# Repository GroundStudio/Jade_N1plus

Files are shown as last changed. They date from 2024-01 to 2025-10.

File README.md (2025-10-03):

GroundStudio Jade N1+
====================================
JadeN1+

Get it from [ardushop.ro](https://ardushop.ro/en/groundstudio/1403-jade-n1-rev100-6427854020598.html)

Explore all the GroundStudio products at [ardushop.ro](https://ardushop.ro/en/37-groundstudio)

Description
-------------------
ATMEGA328PB based development board featuring picoPower® technology for better power management, Peripheral Touch Controller (PTC), 32kBytes of In-System Self-Programmable Flash program memory,  1kBytes EEPROM, 2kBytes Internal SRAM, 9 PWM Channels, 22 Digital Pins, 2 USART, 2 SPI, 2 I²C, 8 ADC Pins with 10 bit Resolution and HT42B534-2 for USB comunication.

Contents
-------------------

* [/Documentation](https://github.com/GroundStudio/Jade_N1plus/tree/main/Documentation) -- Pinout.
* [/Hardware](https://github.com/GroundStudio/Jade_N1plus/tree/main/Hardware) -- Schematics, layout.

Versions
-------------------
*(Not all tags shown)*
- [REV1.0.0]:

License
-------------------

This is released under the [Attribution-ShareAlike 4.0 International (CC BY-SA 4.0)](https://creativecommons.org/licenses/by-sa/4.0/) license. 
**You are welcome to use this for commercial purposes.**

Please consider contributing back to this project or others to help the open-source hardware community continue to thrive and grow! 

Certifications:

[Open Source Hardware Association](https://certification.oshwa.org/ro000023.html)   
   
certification-mark-RO000023-wide (https://certification.oshwa.org/ro000023.html)

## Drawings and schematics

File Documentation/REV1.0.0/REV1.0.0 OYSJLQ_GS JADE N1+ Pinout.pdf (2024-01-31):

# GroundStudio Jade N1+

PC6

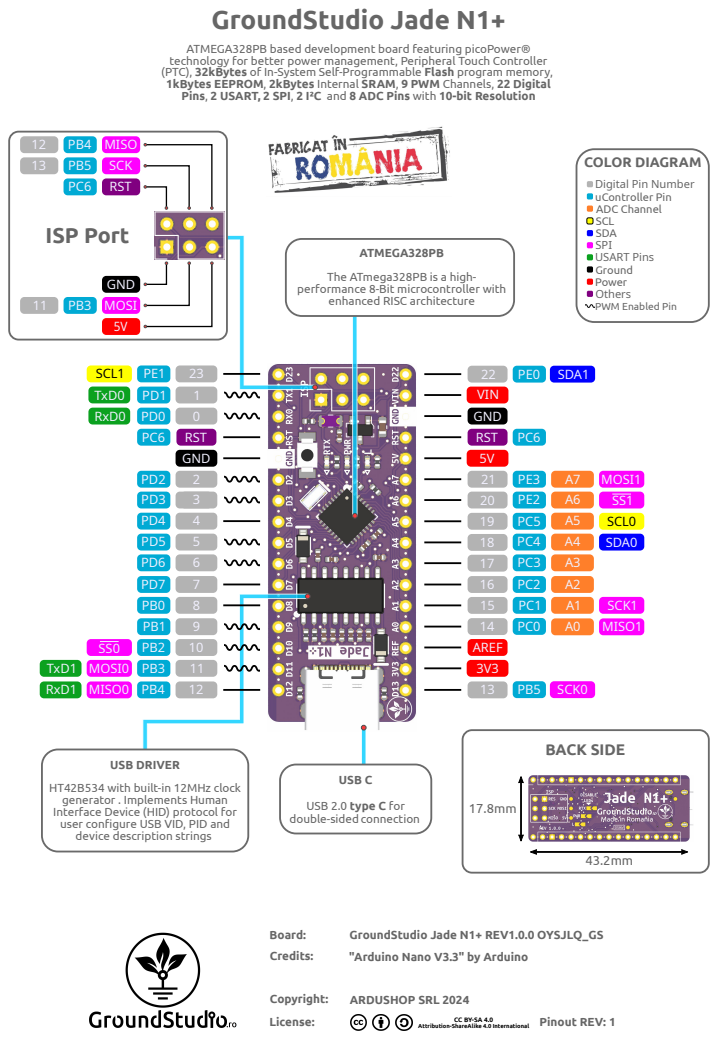
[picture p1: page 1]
SDA1; VIN; GND RST; 17 16 15 14 AREF; PB5 SCK0; MISO0; MOSI0; GND; RST; GND MOSI 5V; SCK; MISO; ISP Port; USB DRIVER; TxD0 RxD0; TxD1 RxD1; SDA0; SCL0; MISO1; MOSI1; SCK1; BACK SIDE; USB C; Board:; Credits:; Copyright:; License:; ARDUSHOP SRL 2024; Pinout REV: 1; SCL1

ATMEGA328PB based development board featuring picoPower®
technology for better power management, Peripheral Touch Controller
(PTC), 32kBytes of In-System Self-Programmable Flash program memory,
1kBytes EEPROM, 2kBytes Internal SRAM, 9 PWM Channels, 22 Digital
Pins, 2 USART, 2 SPI, 2 I²C and 8 ADC Pins with 10-bit Resolution

COLOR DIAGRAM
Digital Pin Number
uController Pin
ADC Channel
SCL
SDA
SPI
USART Pins
Ground
Power
Others
PWM Enabled Pin

ATMEGA328PB
The ATmega328PB is a high-
performance 8-Bit microcontroller with
enhanced RISC architecture

HT42B534 with built-in 12MHz clock
generator . Implements Human
Interface Device (HID) protocol for
user configure USB VID, PID and
device description strings

USB 2.0 type C for
double-sided connection

GroundStudio Jade N1+ REV1.0.0 OYSJLQ_GS
"Arduino Nano V3.3" by Arduino

Attribution-ShareAlike 4.0 International

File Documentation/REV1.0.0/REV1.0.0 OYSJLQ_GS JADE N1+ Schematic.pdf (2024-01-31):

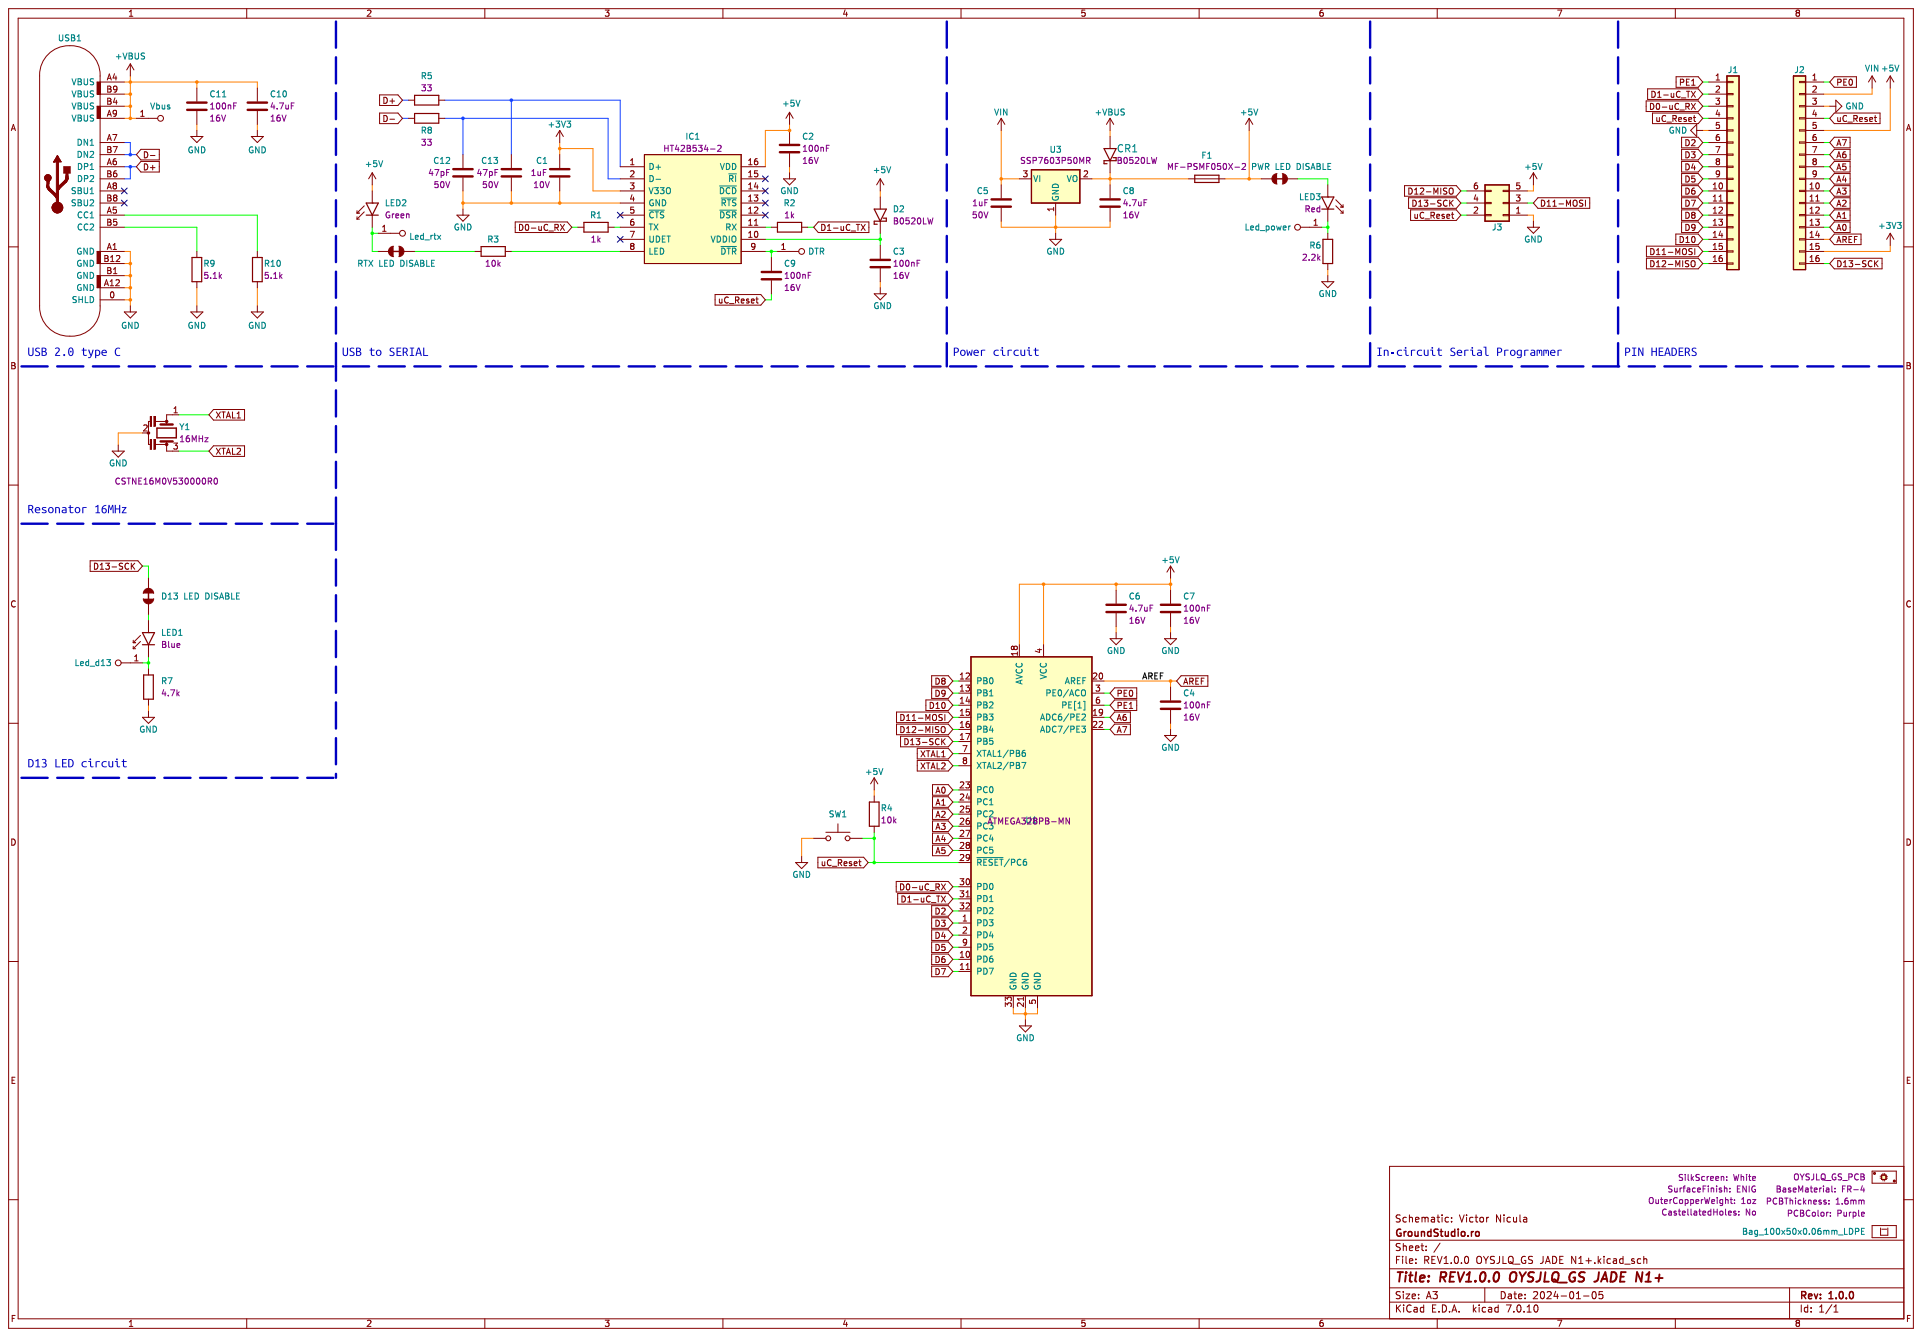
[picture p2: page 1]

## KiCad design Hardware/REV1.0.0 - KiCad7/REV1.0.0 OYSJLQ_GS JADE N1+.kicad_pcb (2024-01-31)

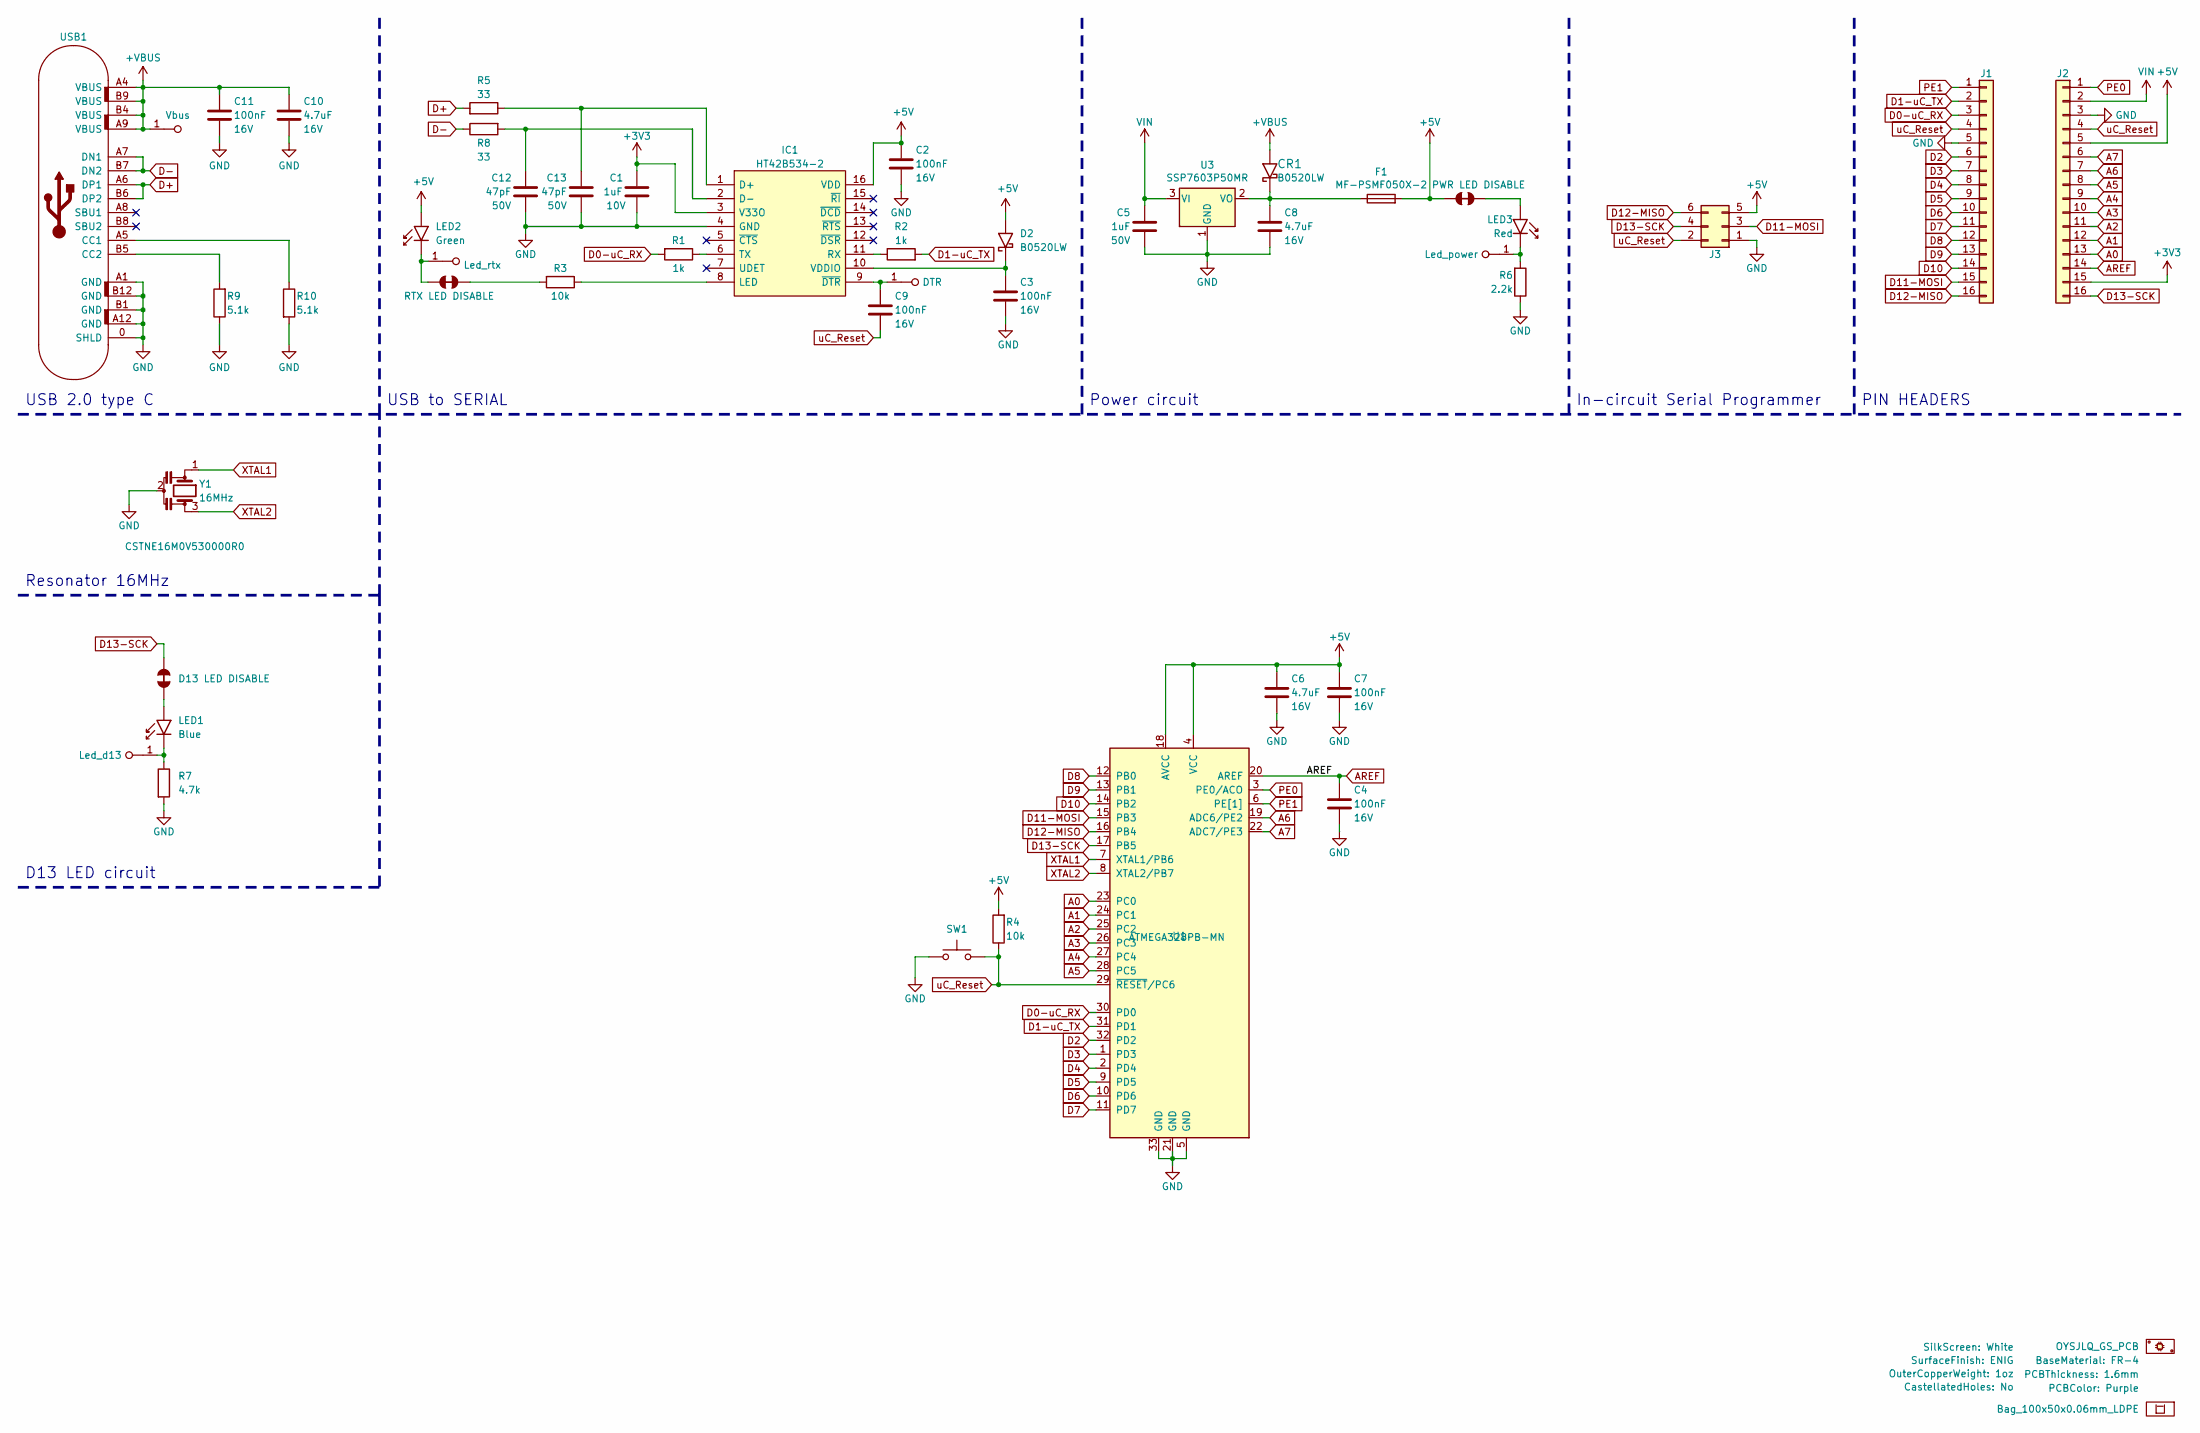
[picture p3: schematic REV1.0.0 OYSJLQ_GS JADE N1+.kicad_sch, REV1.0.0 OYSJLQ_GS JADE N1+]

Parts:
B1: Bag_100x50x0.06mm_LDPE; MPN KFHHEG_B
C1: C_0402_1uF_10V; C_0402_alt; Rated voltage 10V; MPN FS15B105K100PKG; LCSC C525324
C2, C4, C7, C9, C11: C_0402_100nF_16V; C_0402_alt; Rated voltage 16V; MPN 0402B104K160CT; LCSC C83056
C3: C_0402_100nF_16V; C_0402_alt; MPN 0402B104K160CT; LCSC C83056
C5: C_0603_1uF_50V; C_0603; Rated voltage 50V; MPN CL10A105KB8NNNC; LCSC C15849
C6, C8, C10: C_0402_4.7uF_16V; C_0402_alt; Rated voltage 16V; MPN C0402X5R475M160NT; LCSC C729453
C12, C13: C_0402_47pF_50V; C_0402_alt; Rated voltage 50V; MPN FN15N470J500PNG; LCSC C525215
CR1: SOD-123 B0520LW; SOD-123; MPN B0520LW; LCSC C89640
D2: SOD-123 B0520LW; SOD-123; MPN B0520LW; LCSC C89640
F1: Fuse_0805_MF-PSMF050X-2; Fuse_0805; MPN MF-PSMF050X-2; LCSC C116170
IC1: SOP-16_150MIL HT42B534-2; SOP-16_150MIL; MPN HT42B534-2; LCSC C493361
J1, J2: PinHeader_1x16_P2.54_V_M; PinHeader_1x16_P2.54mm_Vertical_Male; MPN KH-2.54PH180-1X16P-L11.5; LCSC C2905491
J3: PinHeader_2x03_P2.54_V_M; PinHeader_2x03_P2.54mm_Vertical_Male; MPN 210-72-03GB01; LCSC C402781
J4: D13 LED DISABLE; SolderJumper_NC_Default
J5: RTX LED DISABLE; SolderJumper_NC_Default
J6: PWR LED DISABLE; SolderJumper_NC_Default
LED1: LED_0402_BLUE; LED_0402_alt; MPN TZ-P2-0402BTIA1-0.45T; LCSC NA
LED2: LED_0402_GREEN; LED_0402_alt; MPN TZ-P2-0402GTIA1-0.45T; LCSC C688877
LED3: LED_0402_RED; LED_0402_alt; MPN TZ-P2-0402RTIA1-0.45T; LCSC C779449
P1: PCB; MPN OYSJLQ_GS_PCB
R1, R2: R_0402_1k; R_0402_alt; MPN RC-02W1001FT; LCSC C226166
R3, R4: R_0402_10k; R_0402_alt; MPN 0402WGJ0103TCE; LCSC C25531
R5, R8: R_0402_33; R_0402_alt; MPN RC-02W33R0FT; LCSC C140161
R6: R_0402_2.2k; R_0402_alt; MPN RC-02W2201FT; LCSC C258093
R7: R_0402_4.7k; R_0402_alt; MPN WR04X4701FTL; LCSC C163826
R9, R10: R_0402_5.1k; R_0402_alt; MPN RC-02W5101FT; LCSC C294638
SW1: TS342A2P-WZ; MPN TS342A2P-WZ; LCSC C557591
TP1: Led_rtx; TestPoint
TP2: Led_power; TestPoint
TP3: Vbus; TestPoint
TP4: Led_d13; TestPoint
TP5: DTR; TestPoint
U1: ATmega328PB-MUR; QFN-32-1EP_5x5_P0.5_EP3.1x3.1; MPN ATMEGA328PB-MN; LCSC C1337164
U3: SOT-23-3 SSP7603P50MR; SOT-23-3; MPN SSP7603P50MR; LCSC C411029
USB1: USB_C_FULL; USB_C_C167321; MPN 918-418K2023S40001; LCSC C167321
Y1: RSN_3P_3.2x1.3 CSTNE16M0V; Rsn_muRata_CSTxE-3Pin_3.2x1.3mm; MPN CSTNE16M0V530000R0; LCSC C341521

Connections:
+3V3: C1.1, IC1.3 (V33O), J2.15
+5V: C2.2, C6.1, C7.1, D2.2 (A), F1.2, IC1.16 (VDD), J2.5, J3.5, J6.2, LED2.2 (A), R4.2, U1.4 (VCC), U1.18 (AVCC)
+VBUS: C10.1, C11.1, CR1.2 (A), TP3.1, USB1.A4 (VBUS), USB1.A9 (VBUS), USB1.B4 (VBUS), USB1.B9 (VBUS)
A0: J2.13, U1.23 (PC0)
A1: J2.12, U1.24 (PC1)
A2: J2.11, U1.25 (PC2)
A3: J2.10, U1.26 (PC3)
A4: J2.9, U1.27 (PC4)
A5: J2.8, U1.28 (PC5)
A6: J2.7, U1.19 (ADC6/PE2)
A7: J2.6, U1.22 (ADC7/PE3)
AREF: C4.1, J2.14, U1.20 (AREF)
D0-uC_RX: J1.3, R1.2, U1.30 (PD0)
D1-uC_TX: J1.2, R2.2, U1.31 (PD1)
D2: J1.6, U1.32 (PD2)
D3: J1.7, U1.1 (PD3)
D4: J1.8, U1.2 (PD4)
D5: J1.9, U1.9 (PD5)
D6: J1.10, U1.10 (PD6)
D7: J1.11, U1.11 (PD7)
D8: J1.12, U1.12 (PB0)
D9: J1.13, U1.13 (PB1)
D10: J1.14, U1.14 (PB2)
D11-MOSI: J1.15, J3.3, U1.15 (PB3)
D12-MISO: J1.16, J3.6, U1.16 (PB4)
D13-SCK: J2.16, J3.4, J4.1, U1.17 (PB5)
D+: R5.2, USB1.A6 (DP1), USB1.B6 (DP2)
D-: R8.1, USB1.A7 (DN1), USB1.B7 (DN2)
GND: C1.2, C2.1, C3.1, C4.2, C5.2, C6.2, C7.2, C8.2, C10.2, C11.2, C12.1, C13.2, IC1.4 (GND), J1.5, J2.3, J3.1, R6.1, R7.2, R9.1, R10.2, SW1.1, U1.5 (GND), U1.21 (GND), U1.33 (GND), U3.1 (GND), USB1.0 (SHLD), USB1.A1 (GND), USB1.A12 (GND), USB1.B1 (GND), USB1.B12 (GND), Y1.2
unnamed: C8.1, CR1.1 (K), F1.1, U3.2 (VO)
unnamed: C3.2, D2.1 (K), IC1.10 (VDDIO)
unnamed: C13.1, IC1.1 (D+), R5.1
unnamed: C12.2, IC1.2 (D-), R8.2
unnamed: IC1.8 (LED), R3.1
unnamed: IC1.11 (RX), R2.1
unnamed: IC1.6 (TX), R1.1
unnamed: C9.2, IC1.9 (~DTR), TP5.1
unnamed: J5.2, R3.2
unnamed: J4.2, LED1.2 (A)
unnamed: LED1.1 (K), R7.1, TP4.1
unnamed: J5.1, LED2.1 (K), TP1.1
unnamed: J6.1, LED3.2 (A)
unnamed: LED3.1 (K), R6.2, TP2.1
unnamed: R10.1, USB1.A5 (CC1)
unnamed: R9.2, USB1.B5 (CC2)
PE0: J2.1, U1.3 (PE0/ACO)
PE1: J1.1, U1.6 (PE[1])
VIN: C5.1, J2.2, U3.3 (VI)
XTAL1: U1.7 (XTAL1/PB6), Y1.1
XTAL2: U1.8 (XTAL2/PB7), Y1.3
uC_Reset: C9.1, J1.4, J2.4, J3.2, R4.1, SW1.2, U1.29 (~RESET/PC6)

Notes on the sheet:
Resonator 16MHz
PIN HEADERS
USB 2.0 type C
Power circuit
D13 LED circuit
In-circuit Serial Programmer
USB to SERIAL

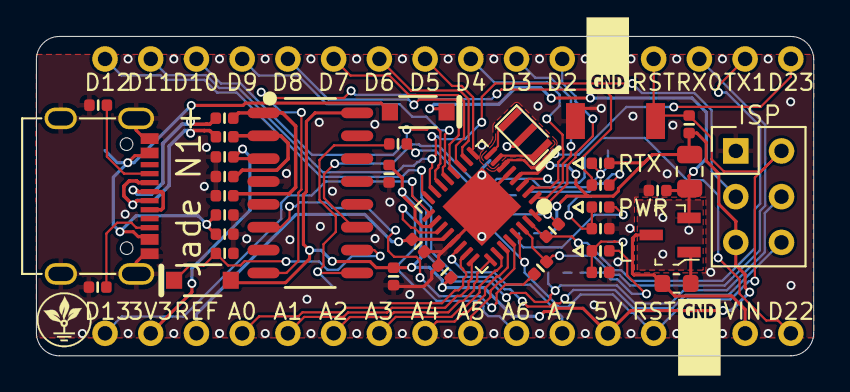
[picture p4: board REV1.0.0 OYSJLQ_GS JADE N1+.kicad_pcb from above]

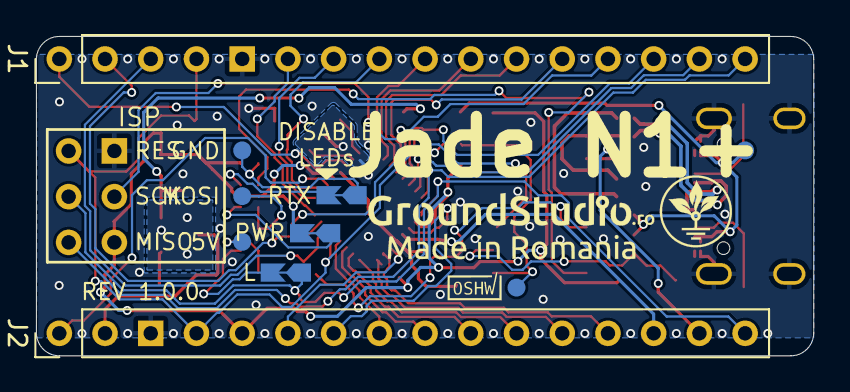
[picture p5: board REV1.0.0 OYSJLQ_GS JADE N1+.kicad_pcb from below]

Board: 2 copper layers, 43.2 x 17.7 mm, 48 parts (5 on the bottom side), 51 nets.

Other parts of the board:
kibuzzard-6597D01D: G***; kibuzzard-6597D01D
kibuzzard-6597D047: G***; kibuzzard-6597D047
